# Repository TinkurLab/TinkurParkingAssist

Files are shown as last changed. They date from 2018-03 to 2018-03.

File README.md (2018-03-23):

# Tinkur Parking Assist

## Overview

Tinkur Parking Assist is a helpful project to help you park your car in the right place in a garage.  After all, you need all that other space for making ;-)

See [LICENSE.md](LICENSE.md) for license info.

## Parts

* Arduino Uno
* [10mm RGB Diffused Common Cathold LED](https://www.sparkfun.com/products/9264)
* [HC-SR04 Ultrasonic Sensor](https://www.sparkfun.com/products/13959)
* Case 3D Print (see [/3D/parking_assist_case/](/3D/parking_assist_case/)) or download from [https://www.thingiverse.com/thing:2836728](https://www.thingiverse.com/thing:2836728)

## Wiring

See [wiring diagram](wiringdiagram.fzz) ([Fritzing software](http://fritzing.org/home/) required).

## Helpful Tutorials
* [Using Common Cathold LEDs](https://learn.adafruit.com/adafruit-arduino-lesson-3-rgb-leds/overview)
* [Parking Sensor Project](https://www.thingiverse.com/thing:2808403)

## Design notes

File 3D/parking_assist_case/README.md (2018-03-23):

# Arduino Case 1

## Overview

## Specs

**3D Model**
[Tinkurcad](https://www.tinkercad.com/things/5iqU6QGvB0J-copy-of-tinkur-parking-assist-case/editv2)

**STL**
See STL file in this directory

Also https://www.thingiverse.com/thing:2836728

Also https://www.tinkercad.com/things/5iqU6QGvB0J-tinkur-park-assist-case

**Slice / Print Settings**
See Simplify 3D FFF file in this directory

**Printer**
Anycubic Kossel Liner Plus

**Filanment**
Hatchbox PLA 1.75mm

## Notes

* v1
    - https://www.tinkercad.com/things/5uq7JSA6oC3-tinkur-parking-assist-case based on remix of another Arduino case
    - Validated Arduino scew hole placement.  Openings for power and USB were too low.  Top slide in track for lid didn't print correctly; likely needed supports.
* v2
    - updated https://www.tinkercad.com/things/5uq7JSA6oC3-tinkur-parking-assist-case.  Moved openings for power and USB.  Added supports using Mesh Mixer.  Added openings for ultrasonic sensors.  
    - Fixed power and USB placement.  Openings for ultrasonic sensors too close by 2mm.  Mesh Mixer supports didn't print well; not all of them adhered to the base; maybe too thin at bottom.
* v3
    - updated https://www.tinkercad.com/things/5uq7JSA6oC3-tinkur-parking-assist-case.  Fixed openings for ultrasonic sensors.  Added opening for LED light.  Switched to Simplify 3D for slicing / supports / printing.
    - Simplify 3D slow default print settings but great quality.  Supports were awesome - generated where needed and not where no needed.  Also easy to add / modify supports.  Also super easy to remove supports; only needed pliers to remove one and only because it was touch to get to with my fingers.  Raft was a bit hard to remove.  Will try printing without for now and adjusting setting later for nother part.  Increasing brim width to compensate for removing raft.  Also there was a bit of warping so perhaps larger brim will help with that too; could also have been the print head being too far away from print bed.
* v4
    - started a new v2 model https://www.tinkercad.com/things/5iqU6QGvB0J-tinkur-parking-assist-case-v2.  Simplified design, removing a ton of combined parts to reduce likelyhood of measurement / combine errors.  Also switch top design from slide in to clip on to reduce need for long wires to connect ultrasonic sensor and led to Arduino.  Increased side of LED hole by 2mm to allow better seating.
    - MVP.  Lid snaps in place well.  Made a mistake for ultrasonic sensor hole size but resulted in the sensor tension mounting which is awesome. 
* v5
    - updated v2 model https://www.tinkercad.com/things/5iqU6QGvB0J-tinkur-parking-assist-case-v2.  Left tension in ultrasonic sensor holes but reduced width.  Also reduced openings around usb and power to reduce opening size.  Also increased internal wall thickness to better snugly hold Arudino as per v1 design.

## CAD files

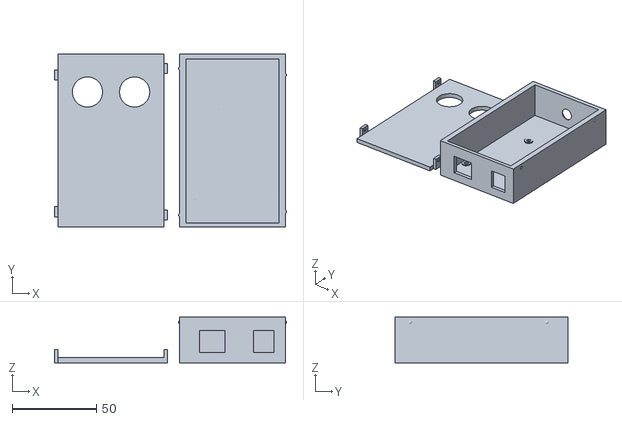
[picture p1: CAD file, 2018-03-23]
3D/parking_assist_case/Tinkur Parking Assist Case v2.stl
137.5 x 102.5 x 27.0

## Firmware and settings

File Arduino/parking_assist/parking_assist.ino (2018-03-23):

//The following tutorials, code, and libraries are used in this project:
// tutorial, code https://www.thingiverse.com/thing:2808403
// library https://github.com/RobTillaart/Arduino/tree/master/libraries/RunningMedian
// tutorial https://github.com/arduino/Arduino/issues/4936 (how to include Arduino library in project folder

#include "src/RunningMedian/RunningMedian.h"

int redPin = 9; 
int greenPin = 10;
int bluePin = 11;
int trigPin = 5; // Sensor Trip pin connected to Arduino pin D5
int echoPin = 6; // Sensor Echo pin connected to Arduino pin D6
long TempDistance = 0; // A variable to store the temporary distance
int counter = 0; // Counter value to check if the object has stopped moving

RunningMedian samples = RunningMedian(3);

//uncomment this line if using a Common Anode LED
#define COMMON_ANODE

void setup(){
  Serial.begin(9600);
  pinMode(trigPin, OUTPUT);
  pinMode(echoPin, INPUT);
  pinMode(redPin, OUTPUT);
  pinMode(greenPin, OUTPUT);
  pinMode(bluePin, OUTPUT);  
}

void loop() {
  long duration, Distance;
  digitalWrite(trigPin, LOW);
  delayMicroseconds(2);
  digitalWrite(trigPin, HIGH);
  delayMicroseconds(10);
  digitalWrite(trigPin, LOW);
  duration = pulseIn(echoPin, HIGH);
  Distance = (duration/2) / 74; // Distance in Inches

  samples.add(Distance);

  int medianDistance = samples.getMedian();

  if(counter < 20){ // Do the rest if the car is still moving
    if (medianDistance < 68 && medianDistance > 36) {
      setColor(255, 255, 0);  // yellow
      Serial.println("case 1");
    } else if (medianDistance <= 36 && medianDistance >= 30) {
      setColor(0, 255, 0);  // green
      Serial.println("case 2");
    } else if (medianDistance < 30) {
      setColor(255, 0, 0);  // red
      Serial.println("case 3");
    } else {
      setColor(0, 0, 0);  // off
      Serial.println("case 4");
    }
  }

  if ((Distance == TempDistance) || ((Distance+1) == TempDistance) || ((Distance-1) == TempDistance)){
    if(counter >= 20){ // Turn off the lights if the object hasn't moved for 20 cycles (no change in distance)
      Serial.println("no movement detected, turning off the lights");
      setColor(0, 0, 0);  // off
    } else {
      counter++;
    }
  } else {
    counter = 0; // Reset counter if there is a movement
  }
  TempDistance = Distance;

  Serial.print("distance inches: ");
  Serial.println(medianDistance); //print the median sensor value
    Serial.print("counter count: ");
  Serial.println(counter); //print the median sensor value
  
  delay(500); //delay 500ms (0.5 second)
}

void setColor(int red, int green, int blue)
{
  #ifdef COMMON_ANODE
    red = 255 - red;
    green = 255 - green;
    blue = 255 - blue;
  #endif
  analogWrite(redPin, red);
  analogWrite(greenPin, green);
  analogWrite(bluePin, blue);  
}

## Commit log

2018-03-17 HC-SR04 ultrasonic, median, and turn off light
2018-03-17 update wiring diagram
    [wiringdiagram.fzz]
2018-03-17 initial case designs
    [arduino_case.stl]
2018-03-18 v4 wip
    [Tinkur Parking Assist Case v2.stl, arduino_case.stl]
2018-03-18 v5 make sure stl is latest
    might not have had all revisions
    [Tinkur Parking Assist Case v2.stl]
2018-03-22 switch pins for colors and tweak distance
